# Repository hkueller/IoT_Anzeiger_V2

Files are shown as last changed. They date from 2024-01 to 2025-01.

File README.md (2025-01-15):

# IOT_Anzeiger

Firmware des IOT_Anzeiger devices, zur Anzeige einiger Daten aus FHEM per esp8266 und einem 4.2 Zoll E-Paper displays.<br>
## Hardware
### ESP8266 mit 4.2 Waveshare Display
Ich verwende für den Aufbau die D1 Boardvariante:<br>
https://www.amazon.de/AZDelivery-D1-Mini-NodeMcu-Parent/dp/B07ZQP9FSX

Als Display kommt ein Waveshare 4.2 E-Ink display zum Einsatz. z.B.:<br>
https://www.amazon.de/Waveshare-Kommunikation-Schnittstelle-Aufl%C3%B6sung-Embedded-Controller/dp/B074NR1SW2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

Obiges Display wird mit einem Adapterkabel geliefert, das sich direkt mit dem D1 Board verbinden lässt.<br><br>

```
Busy -> D2 (GPIO4)
RST  -> D1 (GPIO5)
DC   -> D3 (GPIO0)
CS   -> D8 (GPIO15, SS)
CLK  -> D5 (SCK)
DIN  -> D7 (MOSI)
GND  -> GND
3.3V -> 3.3V
```

Und damit ist die Schaltung auch schon Fertig.<br>

### ESP32
Die Software sollte grundsätzlich auch mit einem ESP32 Funktionieren. Hier werden allerdings noch einige Anpassungen bei den Defines und includes notwendig sein!<br>
### Andere Displays
Sofern diese mit den Waveshare Displays kompatibel sind, sollten diese Funktionieren.
wenn in `config.h` die korrekten Werte eingetragen werden.<br>
### Gehäuse
Im Verzeichniss `Case_3DDruck` befinden sich Freecad Daten für ein Gehäuse sammt Deckel und Ständer.
Der Ständer wird dabei am Geäuseboden angeschraubt - dazu sind kleine Selbstschneidende Schrauben Notwendig,
die auch für den Deckel verwendet werden sollten.
## konfiguration der Software
Vor dem Kompilieren der Firmware bitte einen Blick in `config.h` werfen.<br>
Hier sind einige Konfigurierbare Optionen.<br>
z.B. könnte man ein 7 Zoll mit üblicherweise 800x600 Auflösung verwenden.<br>
in dem Fall die Defines:<br>
```
#define DISPLAY_HEIGHT 400
#define DISPLAY_WIDTH 300
```
Entsprechend anpassen.<br>

Auch wird hier der Hostname des FHEM Servers, mqtt servers, NTP Server usw. eingestellt.<br>

Auch sollte ein Blick in `platformio.init` geworfen werden.<br>
Per default versucht das einen OTA Upload der Firmware. Ist das nicht erwünscht müssen die Zeilen:<br>
```
upload_protocol = espota
upload_port = display.wlan.compuextreme.de
upload_flags =
        --port=8266
```
auskommentiert werden!<br>

Nach dem anpassen, kann die Software unter Linux mit code/platformio übersetzt werden:
```
# pio run -t upload
```

## Netwerk Setup
In dem Projekt wird der WifiManager für das Netzwerk Setup verwendet.<br>
Eine Dokumentation hierzu gibt es im Internet:<br>

https://github.com/tzapu/WiFiManager.git

ist dem ESP keine Netzwerkkonfig bekannt, meldet dieser sich als AccessPoint mit der SSID "IOTAnzeiger".<br>
Mit diesem muss man sich Verbinden, und dann der Dokumentation des WiFiManager Projektes folgen.<br>

## configuration in FHEM
Zur Verwendung von IOT_Anzeiger_V2 ist ein MQTT Server notwendig.
Hier kann jeder beliebige MQTT Server verwendet werden. Der Einfachheit halber hier
das Setup eine solchen in FHEM (fhem liefert einen integrierten MQTT mit - dazu gibt es mehr im fhem wiki)
```
define mqtt2server MQTT_SERVER 1883 global
```

Wichtig: vor dem Übersetzen die Netzwerk Konfiguration (fhem-server, mqtt) anpassen!<br>
Dies wird in der config.h erledigt:<br>

`FHEM_HOST` -> hier wird die IP oder der Hostname der FHEM Instanz eingetragen<br>
`FHEM_PORT` -> Telnet Port Nummer der FHEM Instanz (default: 7072)<br>
`MQTT_SERVER` -> IP oder Hostname des MQTT Servers (FHEM Internet MQTT = Identisch to FHEM_HOST)<br>
`MQTT_REQUEST_TOPIC` -> Entspricht dem Topic, an welches ein `true` geschickt wird,<br>
                wenn das Display die Konfiguration von FHEM erfraegt.<br>
`MQTT_SUBSCRIBE_TOPIC` -> Wichtig, dass alle nachrichten des basic Topic (for dem "/") abgeholt werden ("+")<br>

IOT_Anzeiger_V2 Verwendet ein MQTT2 Device in FHEM, sowie die Telnet Schnittstelle von FHEM.<br>
MQTT1 wird verwendet um die Initiale Konfiguration zu laden, Telnet um Readings von Geräten abzufragen.<br>
Aktuell wird nur eine Textausgabe ohne Grafiken unterstützt.<br>

Das Fhem Gerät lässt ich folgendermassen erstellen:<br>
```
define <displaname> MQTT2_DEVICE <your mqtt server>
attr <displayname> readingList display/get_config:* RequestConfig
attr <displayname> userReadings SetConfig:RequestConfig.* {
    if ( ReadingsVal($name,RequestConfig",0) eq "true") {
        fhem("set <mqtt2server> publish display/conf "\"<Orientation>,<FontSize>\"");
        fhem("set <mqtt2server> publish display/dash "\"<numofdashes>,<linenumber>,<linenumer>,...\"");
        fhem("set <mqtt2server> publish display/line_0 "\"Name, <fhem_device>, <reading>, <Einheit>, <position>\"");
        #put additional config lines here
        fhem("set <mqtt2server> publish display/conf_done \"true\"");
    }
}
```
Natürlich kann hier jedes Kommando (achtung: Perl Syntax) eingesetzt werden, das einem mqtt server Daten schickt.<br>

`display/line_0` ist dabei das sogenannte Topic.<br>

### mqtt topic `display/conf`:<br>
`"0,24"` -> Vertikale Ausrichtung, Fontgrösse 24<br>

-> die erste Ziffer gibt die Ausrichtung des Displays an. 0 Entspricht dabei Querformat, 3 Hochformat.<br>
-> die zweite Ziffer gibt die Fontgrösse an. Verwendet werden können 8,12,16,20 und 24.<br>

### mqtt topic `display/dash`:<br>
Hiermit kann das Display mit Horizontalen Linien Unterteilt werden.<br>
`"2,5,9"` -> Es werden 2 Horizontalen Linien gezeichnet, Eine zwischen der 5. und 6. Zeile, eine zwischen der 9. und 10. Zeile<br>
dabei wird mit der ersten Zahl die Anzahl der horizontalen Linien angegeben. Danach müssen kommagetrennt ganuso viele Ziffern folgen,<br>
die jeweils Zeilennummern, nach denen die Linie gezeichnet werden soll, entsprechen.<br>

### mqtt topic `display/line_\<linenumber\>`:<br>
`"Solarertrag,E3DC,power,W,3"` <br>
Solarertrag -> Bezeichner wird linksbündig in der Zeile (mit 3 Pixel abstand vom Rand) dargestellt<br>
E3DC->Gerätename in fhem welcher abgefragt wird.<br>
power -> Reading des Gerätes, das den Gewünschten Wert Enthält<br>
Das Reading wird rechtbündig angezeigt - mit Platz für die Einheit.<br>
W -> Einheit (sollte nicht mehr als 3 Zeichen enthalten)<br><br>

Enthält der Sting mehrere Daten getrennt durch "," Werden diese folgend ausgewertet:<br><br>
`<Name>[,<fhem_device>,<reading>,[<Einheit>],<position>]`<br>
Name = Titel der auf dem Display Linksbündig (position beachten) in der Zeile dargestellt wird.<br>
fhem_device = Device name in FHEM von welchem das Reading verwendet werden soll <br>
reading = Reading des fhem_device, welches die gewünschten Daten liefert<br>
Einheit = Wenn angegeben wird der String hinter den Daten angezeigt (Einheit des Wertes)<br>
position = Name wird um anzahl <position> zeichen nach Rechts eingerückt<br><br>

`"Wetterinformationen"`<br>
Enthält der Eintrag nur einen String, wird dieser als Headline erkannt, und in der Zeile Mittig Platziert.<br><br>

Dazu gild noch, das linenumber 0 (also `display/line_0`) eine Sonderfunktion hat. <br>
Dargestellt werden auf dem Display nur Headline Einträge. In dieser Zeile wird der String Linksbündig dargestellt,
und Rechtbündig noch Datum und Uhzeit der letzten Datenaktualisierung hinzugefügt.<br>
Andere Einträge, die mit fhem Device und Reading angegeben werden, werden ausschliesslich auf der <br>
Website (nur http (port 80)), die von dem Device ausgeliefert wird, dargestellt.<br>

### mqtt topic `display/conf_done`:<br>
Das sollte nach abschluss aller konfigurations Daten gesendet werden.<br>
Das sorgt dafür das der Config Modus beendet wird, Die Werte von FHEM geholt werden,
und das E-Ink Display mit den Daten upgedated wird.

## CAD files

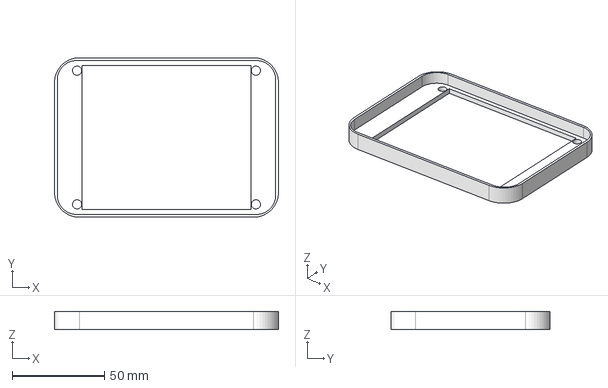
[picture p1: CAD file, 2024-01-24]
Case_3DDruck/Gehaeuse_Deckel_V2.FCStd
121.5 x 86.5 x 10.0 mm

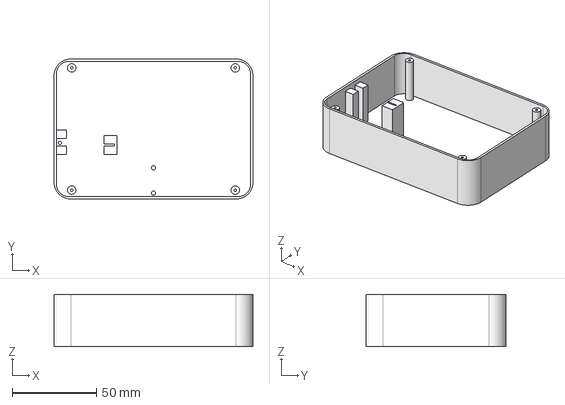
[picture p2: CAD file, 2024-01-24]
Case_3DDruck/Gehaeuse_Boden_V2.FCStd
118.0 x 83.0 x 31.0 mm

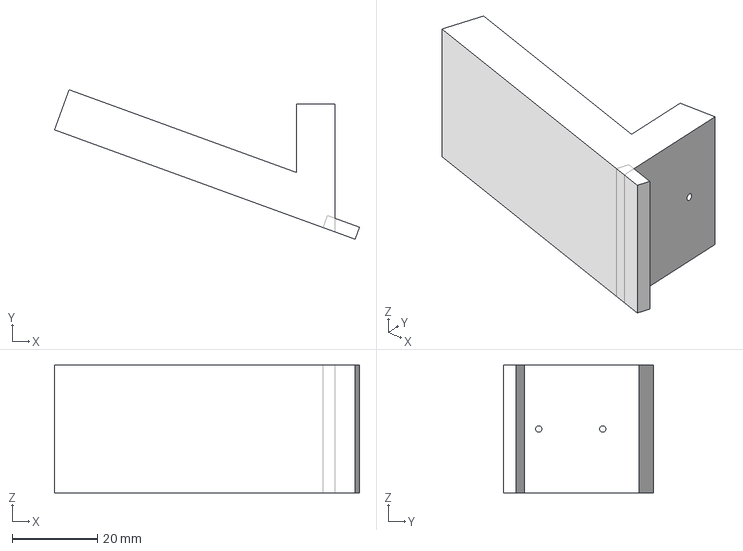
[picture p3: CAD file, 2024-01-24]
Case_3DDruck/Staender.FCStd
71.5 x 35.0 x 30.0 mm

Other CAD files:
Case_3DDruck/Gehaeuse_Boden_V2.stl
Case_3DDruck/Gehaeuse_Deckel_V2.stl
Case_3DDruck/Staender.stl

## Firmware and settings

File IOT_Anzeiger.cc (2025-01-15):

/**
 *  @filename   :   IOT_Anzeiger.cc
 *  @brief      :   Display some Values gethared from FHEM (WLAN)
 *  @author     :   Harald Küller
 *
 *  Copyright (C) Waveshare     November 6 2021
 *
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
 * THE SOFTWARE IS PROVIDED "AS IS", WITHOUT WARRANTY OF ANY KIND, EXPRESS OR
 * IMPLIED, INCLUDING BUT NOT LIMITED TO THE WARRANTIES OF MERCHANTABILITY,
 * FITNESS OR A PARTICULAR PURPOSE AND NONINFRINGEMENT. IN NO EVENT SHALL THE
 * AUTHORS OR COPYRIGHT HOLDERS BE LIABLE FOR ANY CLAIM, DAMAGES OR OTHER
 * LIABILITY WHETHER IN AN ACTION OF CONTRACT, TORT OR OTHERWISE, ARISING FROM,
 * OUT OF OR IN CONNECTION WITH THE SOFTWARE OR THE USE OR OTHER DEALINGS IN
 * THE SOFTWARE.
 */

#include <SPI.h>
#include <Display.h>
#include <Network.h>
#include <Data.h>

smarthome sm;
display disp;
network net;
bool mutex=false;
bool firstrun=true;

void setup() {
	// put your setup code here, to run once:
	// add Display Data
	//bool add(String show_name, String fhem_dev, String fhem_reading, int disp_line); 
#ifdef DEBUG
	//delay(10000);
	Serial.begin(115200);
	Serial.println("Setup starting");
#endif
	disp.begin(&sm);
#ifdef DEBUG
	Serial.begin(115200);
#endif
#ifdef DEBUG
	Serial.println("Starting Network");
	Serial.flush();
#endif
	disp.Message("Starting up Network", &sm);
	net.begin();
	disp.Message("Network Up", &sm);
	if(! sm.SetFirst()) {
		disp.Message("Waiting for config data",&sm);
	}
#ifdef DEBUG
	Serial.println("Setup completed");
	Serial.flush();
#endif
}

void loop() {
	int mqtt_return;

	if ( mutex ) {
		yield();
		return;
	}
	// put your main code here, to run repeatedly:
	if ( net.testNet(&disp, &sm) == 1 ) {
#ifdef DEBUG
		Serial.println("Network Restarted");
		Serial.println("Loading FHEM Data");
		Serial.flush();
#endif
		net.UpdateData(&disp,&sm);
#ifdef DEBUG
		Serial.println("Updating Display");
		Serial.flush();
#endif
		disp.updatelast();
	}
/*#ifdef DEBUG
	Serial.println("Handle Net");
	Serial.flush();
#endif*/
	net.handleNet(&sm, &disp);
	if(sm.SetFirst() == true) {
		if ( disp.GetUpdate() == true) {
#ifdef DEBUG
			Serial.println("Update Display");
			Serial.flush();
#endif
			disp.LoadFrame(&sm);
#ifdef DEBUG
			Serial.println("Update Updatetime");
			Serial.flush();
#endif
			disp.updatelast();
			yield();
		}
	}
	mqtt_return=sm.HandleMQTT();
	switch(mqtt_return) {
		case 1:
			disp.updatelast();
			yield();
			break;
		case 2:
			net.UpdateData(&disp,&sm);
			net.ConfigDone();
			disp.EnableUpdate();
			yield();
			break;
	}
}

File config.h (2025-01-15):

#ifndef __CONFIG_H
#define __CONFIG_H

//#define DEBUG
/*
 * Network Setup
 */

//NTP Time Server Setup
//#define MY_NTP_SERVER "at.pool.ntp.org"
#define MY_NTP_SERVER "ladon.compuextreme.de"
#define MY_TZ "CET-1CEST,M3.5.0,M10.5.0/3"
//define the access to the FHEM Server
#define FHEM_HOST "rahanas.wlan.compuextreme.de"
#define FHEM_PORT 7072
#define FHEM_RETRY 2
//define what is needed for mqtt config access
#define MQTT_SERVER "rahanas.wlan.compuextreme.de"
#define MQTT_PORT 1883
#define MQTT_REQUEST_TOPIC "display/get_config"
#define MQTT_SUBSCRIBE_TOPIC "display/+"
#define MQTT_DEPTH 40
/*
 * Display Setup
 */
//4.2" Waveshare E-Ink
#define DISPLAY_HEIGHT 400
#define DISPLAY_WIDTH 300
//define intervall to pull updates out of the fhem server
#define UPDATE_MINUTE 1
#define APSID "IOT Anzeiger"
#endif

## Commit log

2022-12-29 OTA Update wieder aktiviert. Funktion zur plazierung der Anzuzeigenden Werte und Überschriften erstellt, die Zeilenorientiert arbeitet. Wallbox Watt und Heizungsstatus hinzugfügt
2022-12-31 LANDSCAPE Mode, und Fontgrössen 12 und 8 hinzugfügt
2022-12-31 FHEM Abfrage robuster gebaut (am ende befindliche whitespaces sind kein problem mehr). Neue Werte von FHEM abgefragt für wallbox leistung, Heizungsstatus, Lagervolumen angabe des Brenners...
    [Network.cc]
2023-01-14 Startup Reihenfolge geändert. 1. Status, 2. Netzwerk, 3. NetDone(), und dann Anzeige derr Daten
2023-01-14 Manuelles Update der neuen Werte per port 5023 (telnet) eingepflegt
2023-03-30 Systemzeit wird jetzt per ntp gesetzt, und update zeiten per ntp zeit upgedated
2023-12-08 Batterie load wird nun mit 2 Stellen hinter dem Komma angezeigt, Temperatur ist nun das Reading mit Durchschnittstemp der beiden Aussensensoren
2023-12-18 Update der Display driver codes
2024-01-12 Revert "Update der Display driver codes"
    This reverts commit 9e8ce3d7e3b52ab4de4b353aa991d5e7324be211.
    -> seems the new epd drivers are instable
2024-01-14 some bugfixes, Added some additional values to Website, change Bat val to floating point
    [Display.cc]
2024-01-16 Vieles umgeschrieben. smarthome klasse für die Konfiguration neu erstellt, display und network klassen daran angepasst. ftp schnittstelle ist jetzt geschichte.
2024-01-24 Added FreeCad and stl files for a case
    [Gehaeuse_Boden_V2.FCStd, Gehaeuse_Boden_V2.stl, Gehaeuse_Deckel_V2.FCStd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]
2024-01-24 completed, added case
2024-01-25 cleaned up source, removed unused memberfunctions, fixed some memberfunction calles
    [Data.cc, Data.h, Display.cc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]
2024-02-04 Headlines are now shown with inverted colores
    [Display.cc]
2024-02-04 bugfix: Config reload every 10 minutes does now work
    [Network.cc]
2025-01-15 some fixes in debugging output
    [Display.cc]
2025-01-15 some bugfixes, additional new mqtt handler function
    [Data.cc, Data.h]
2025-01-15 fixed problem with hanging fhem reconnects
    [Network.cc]
